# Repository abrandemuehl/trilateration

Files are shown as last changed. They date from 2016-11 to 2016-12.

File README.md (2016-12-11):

# Attempted ESP8266 Based WiFi Trilateration

This was a project done for UIUC's ECE 445 - Senior Design.

This project does not trilaterate positions succesfully - code for communication is still needed.

The program writes the MAC address and the associated RSSI of packets received in promiscuous mode to the UART connection at 115200 BAUD.
The messages are in a binary format found in `common/messages.h`.
They are read back by the PC program and displayed like so
```
WIFI:   6c:72:e7:d1:12:4d 40
Serial: 6c:72:e7:d1:12:4d 40
WIFI:   6c:72:e7:d1:12:4d 40
Serial: 6c:72:e7:d1:12:4d 40
WIFI:   6c:72:e7:d1:12:4d 40
Serial: 6c:72:e7:d1:12:4d 40
WIFI:   6c:72:e7:d1:12:4d 40
Serial: 6c:72:e7:d1:12:4d 40
WIFI:   6c:72:e7:d1:12:4d 40
Serial: 6c:72:e7:d1:3f:e2 6
WIFI:   6c:72:e7:d1:3f:e2 6
Serial: 6c:72:e7:d1:3f:e2 6
WIFI:   6c:72:e7:d1:3f:e2 6
Serial: 40:78:e7:d1:3f:e2 6
WIFI:   40:78:e7:d1:3f:e2 6
Serial: 2c:78:e7:d1:3f:e2 6
```
Messages prefaced with `WiFi` were received by the incomplete communication code.
The `Serial` came from the ESP8266.

There are some useful code snippets that can be used in other ESP8266 based projects.
The hardware design files also might be somewhat useful for reference.

The original goal of the project was to create a way to track WiFi devices indoors.
Our strategy was to enter promiscuous mode, and look at the RSSI of received packets, and use that to estimate the distance of the transmitting device from the ESP.

Boards were designed as part of the requirements for the class, but they are almost hardware equivalent to most simple ESP modules that you can purchase online for a lower price...
Also, the boards that we created have problems that we couldn't track down. We're pretty sure they were caused by poor fabrication, but there may be some flaw in the original designs.

## Building and running

Note: These instructions are for linux only.
We ran into issues with the toolchain on Mac that had to do with the size of the binary created not fitting into iram.

First, clone with the submodules included
```bash
$ git clone --recursive https://github.com/abrandemuehl/trilateration.git
```
Or, if you've already cloned it without submodules, use
```bash
$ git submodule update --init --recursive
```

Then, edit the makefile for the submodule [esp-open-sdk](https://github.com/pfalcon/esp-open-sdk) to use the 0.9.4 version.
This can be done by editing the line that says
```
VENDOR_SDK = x.x.x
```
to be
```
VENDOR_SDK = 0.9.4
```
then run `make` in the esp/esp-open-sdk directory. (This step takes a while)

Once that is complete, you can build the main app.

First, create a directory to hold the binary files `mkdir esp/bin`.

To build the main application, you first have to `source .env` to get the paths of the toolchain commands.
Once you've done that, run `make` in the `esp` directory.

Then you can run `make flash` to use the esptool to flash it onto the ESP8266 module of your choice that is in program mode.

## Strategy
Trilateration is a pretty simple concept.
You have 3 spheres in space with known radii, and you want to find the intersection point of all of the surfaces of the spheres.
You can use this strategy to get the location of a point, given the centers and radii of 3 spheres where the point lies on their surfaces.

See the [wikipedia](https://en.wikipedia.org/wiki/Trilateration) article and [this stackoverflow question](http://stackoverflow.com/questions/16176656/trilateration-and-locating-the-point-x-y-z) for more information about the algorithm.

The exact trilateration algorithm is implemented in `common/trilatertion.c`.

## ESP Specific Code

#### Promiscuous mode and MAC addresses
In order to use communicate the positions and radii of the circles estimated from the RSSI, each device must be identifiable through some means.
We chose the MAC address of devices, as this is *supposed* to be unique per device.
However, the information given to the promiscuous_rx_cb by the SDK is very limited on SDK versions >= 0.9.5.
It only passes some basic information about the packet to the callback, which does not include anything that can be used to identify the sender.
I'm not sure why they removed this functionality, but it exists in the SDK version 0.9.4, so we chose to use it.

When using SDK 0.9.4, we can get the whole 802.11 header of the packet, making it easy to get the MAC address of the sender and destination devices.
The basic structure of 802.11 packets is shown in `esp/network_80211.h` which we modified from the version found at https://github.com/ly0/esp8266-smartlink.
We added the structure of data frames, since that was what we wanted to use.

#### STATION mode and Promiscuous mode
The big problem we ran into with promiscuous mode was that the ESP must be in STATION mode for promiscuous mode to work.
This was a problem for our original design, since we planned to use the mesh networking capabilities of the ESP to communicate the positions and radii of the circles used for trilateration.

#### `rst cause:4`
Another problem we found was that the promiscuous mode callback runs at a high priority.
So, when you get more packets than you can process, the promiscuous callback will starve some other important task in the SDK (not sure which one) and cause a watchdog timer to reset the device.
The reset will cause the device to write `rst cause:4, boot mode: (x, x)` to the UART connection.
The `cause:4` indicates that the reset was caused by a watchdog timer going off, as documented [here](http://www.esp8266.com/viewtopic.php?p=2096#p2112).

The only way to mitigate this reset problem is to do less work in the promiscuous mode callback.
This doesn't mean you have to do less work total, you just need to delegate it to a lower priority task.

In the ESP sdk, tasks can be defined with the following lines of code
```C
#define message_procTaskPrio        1
#define message_procTaskQueueLen    2
os_event_t message_procTaskQueue[message_procTaskQueueLen];
static void message_procTask(os_event_t *event);

void ICACHE_FLASH_ATTR
user_init() {
  ...
  // Defines a task that can be started with system_os_post
  system_os_task(message_procTask, message_procTaskPrio,
                 message_procTaskQueue, message_procTaskQueueLen);
  ...
}
```

This defines, the task, but doesn't run it.
To run a task, run system_os_post in your promicuous mode callback.
```
void ICACHE_FLASH_ATTR
promisc_cb(uint8_t *buf, uint16_t len) {
  ...
  system_os_post(message_procTaskPrio, 0, 0);
  ...
}
```
When `system_os_post` is called, it will queue up the message processing task to be run once the CPU frees up from all of the system tasks that run at higher priority.

How you pass data to this task is up to you.
I used a ring buffer, but I didn't make it thread safe, so there are race conditions in there.

## PC Code

The PC code was added because of the STATION mode problem with promiscuous mode.
Without access points to connect to, each board would not be able to communicate with the other ones, making trilateration impossible.
We didn't want to require that the devices connect to a network, so we planned to send messages over USB to a laptop, then have the laptop broadcast the values.
We ran out of time before we could test if this method would work.

## Trilateration Problems
The trilateration algorithm and code that we had intended to use would not with real values based on RSSI.
The algorithm solves a system of equations using the spheres, but only finds a solution if they intersect at only one point.
This is not a good algorithm because it doesn't find a solution when the estimated spheres don't exactly line up, which won't happen in almost all cases.

## In conclusion

We ran out of time and couldn't finish the project for the class.
We have no intentions of working on this code again, but if you have any questions about the choices made in the code, feel free to open an issue.

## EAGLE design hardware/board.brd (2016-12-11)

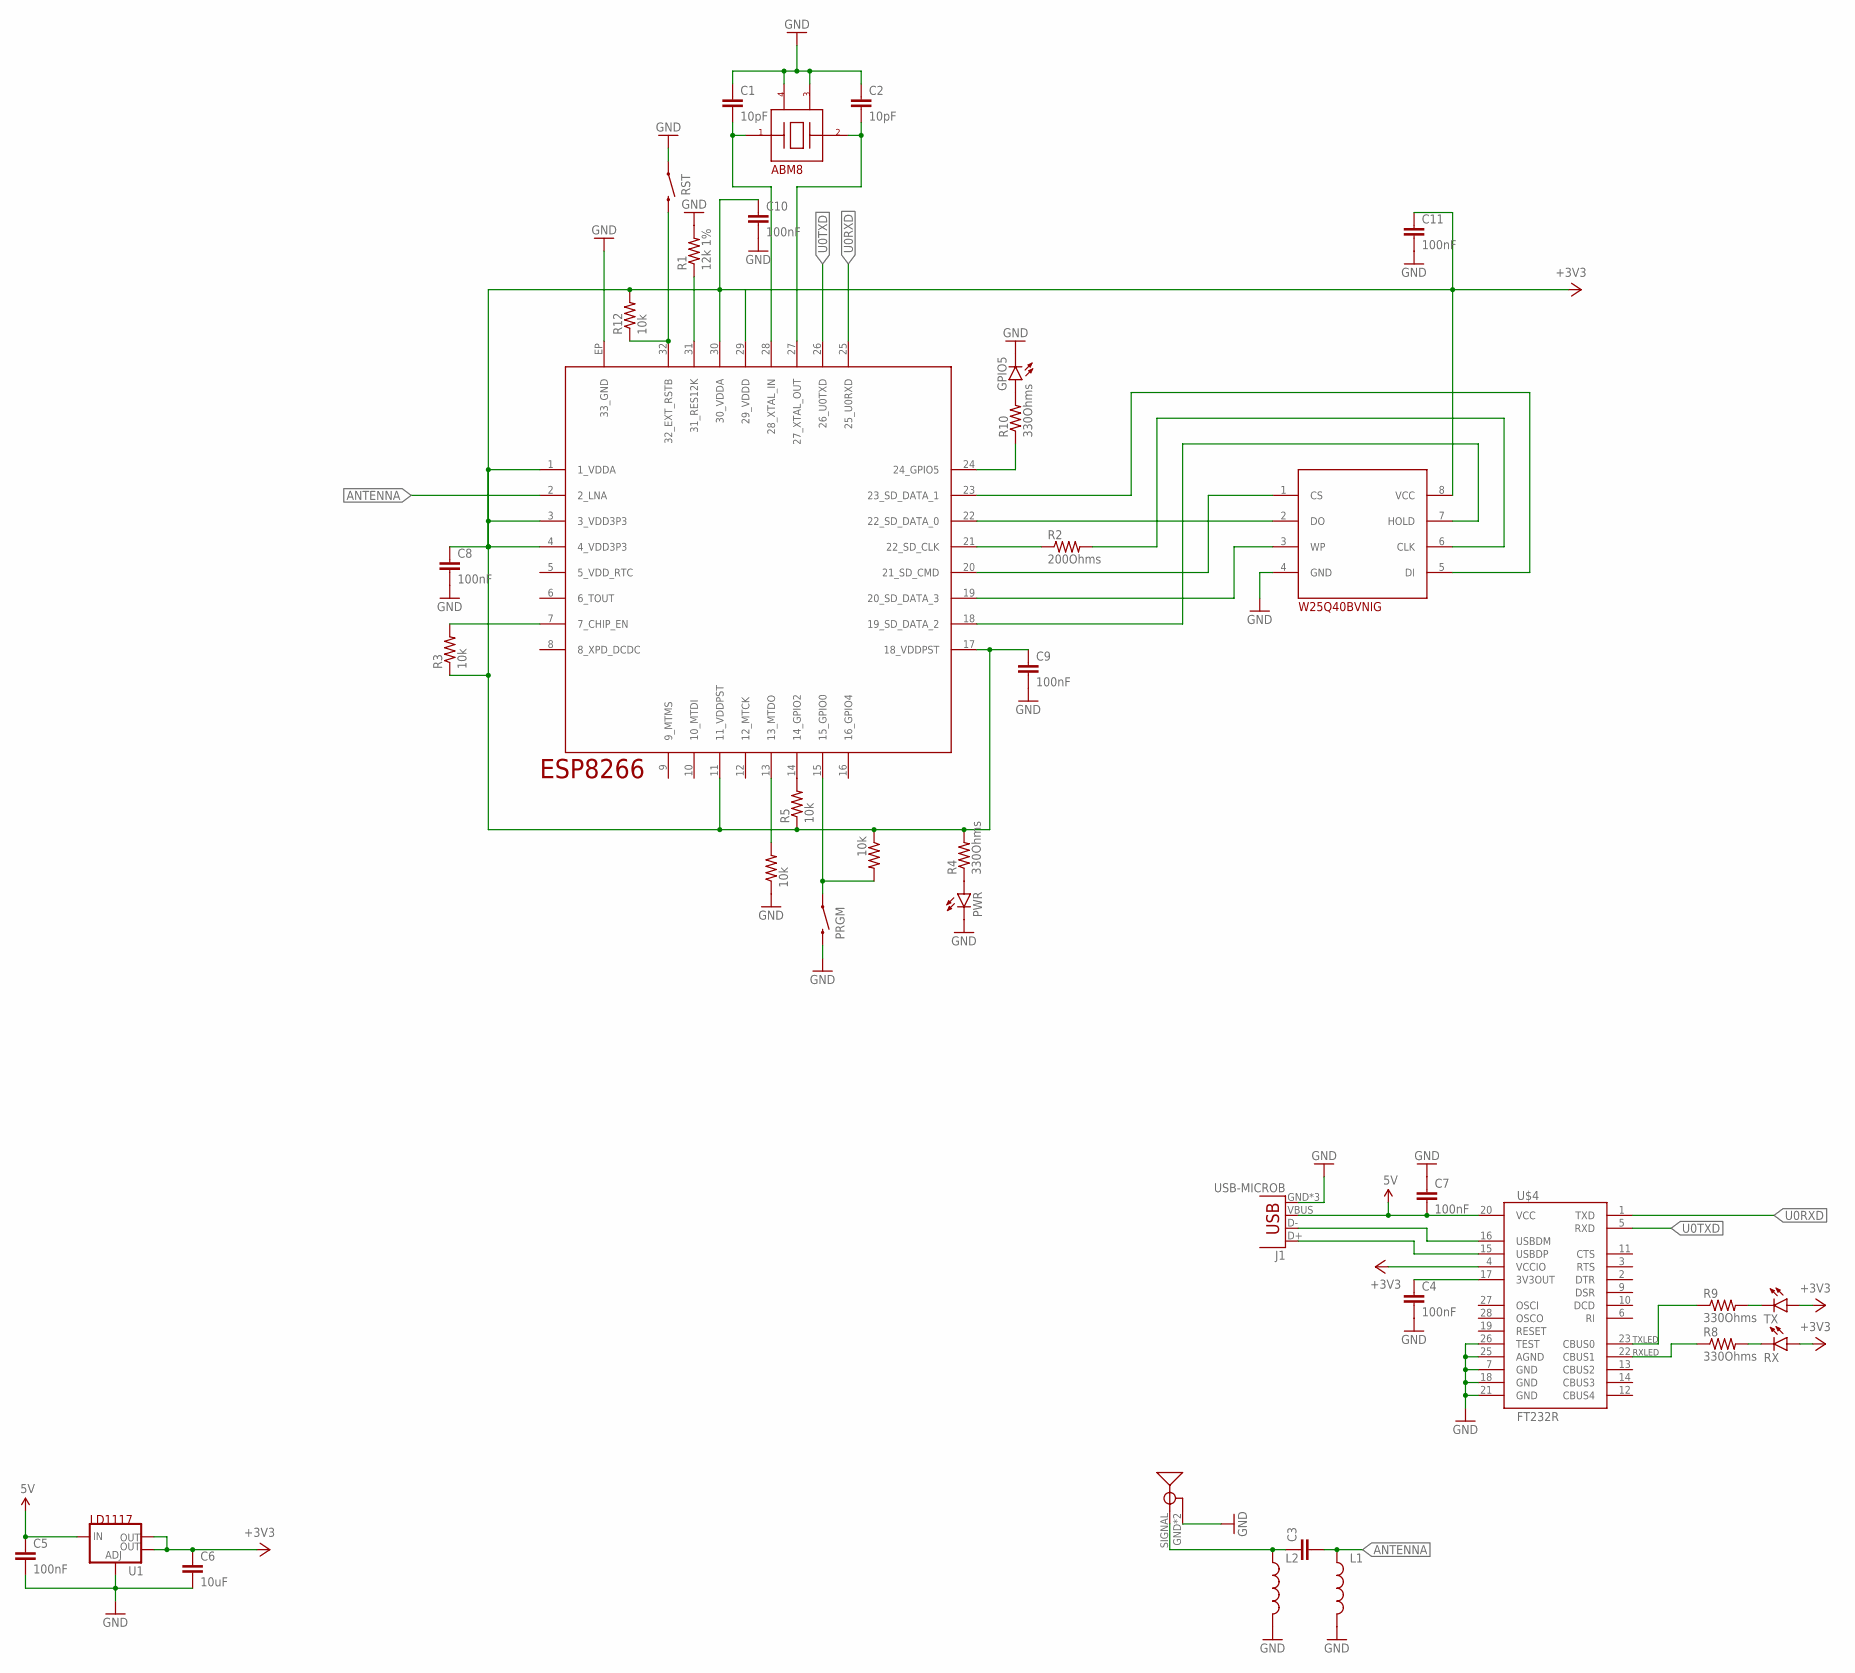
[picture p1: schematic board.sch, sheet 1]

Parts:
C1, C2: 10pF; 0603-CAP
C3: CAP0402-CAP; 0402-CAP
C4, C5, C7, C8, C9, C10, C11: 100nF; 0603-CAP
C6: 10uF; 0603-CAP
GPIO5: LED0603; LED-0603
J1: USB-MICROB
L1, L2: INDUCTOR0402; C0402
PRGM: SWITCH-MOMENTARY-2PTH; TACTILE-PTH
PWR: LED0603; LED-0603
R1: 12k 1%; 0603-RES
R2: 200Ohms; 0402-RES
R3, R5, R6, R7, R12: 10k; 0603-RES
R4, R8, R9, R10: 330Ohms; 0603-RES
RST: SWITCH-MOMENTARY-2PTH; TACTILE-PTH
RX: LED0603; LED-0603
TX: LED0603; LED-0603
U1: V_REG_LM1117SOT223; SOT223
U$1: W25Q40BVNIG; SOIC-8
U$2: ESP8266; QFN-32
U$3: ABM8
U$4: FT232R; SSOP-28
U$5: OMNIANTENNA; ANTENNA

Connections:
+3V3: C6.1, C8.1, C9.1, C10.1, C11.1, R3.1, R4.2, R5.1, R6.1, R12.2, RX.A, TX.A, U1.2 (OUT), U1.4 (OUT), U$1.8 (VCC), U$2.1 (1_VDDA), U$2.3 (3_VDD3P3), U$2.4 (4_VDD3P3), U$2.11 (11_VDDPST), U$2.17 (18_VDDPST), U$2.29 (29_VDDD), U$2.30 (30_VDDA), U$4.4 (VCCIO)
ANTENNA: C3.2, L1.1, U$2.2 (2_LNA)
GND: C1.1, C2.1, C4.2, C5.2, C6.2, C7.1, C8.2, C9.2, C10.2, C11.2, GPIO5.C, J1.GND, J1.MT1 (GND), J1.MT2 (GND), L1.2, L2.2, PRGM.3 (2), PWR.C, R1.2, R7.1, RST.1, U1.1 (ADJ), U$1.4 (GND), U$2.EP (33_GND), U$3.P$2 (GND), U$3.P$4 (GND2), U$4.7 (GND), U$4.18 (GND), U$4.21 (GND), U$4.25 (AGND), U$4.26 (TEST), U$5.GND, U$5.GND1 (GND)
unnamed: R2.2, U$1.6 (CLK)
unnamed: U$1.2 (DO), U$2.22 (22_SD_DATA_0)
unnamed: U$1.5 (DI), U$2.23 (23_SD_DATA_1)
unnamed: U$1.7 (HOLD), U$2.18 (19_SD_DATA_2)
unnamed: R1.1, U$2.31 (31_RES12K)
unnamed: U$1.3 (WP), U$2.19 (20_SD_DATA_3)
unnamed: U$1.1 (CS), U$2.20 (21_SD_CMD)
unnamed: R2.1, U$2.21 (22_SD_CLK)
unnamed: C3.1, L2.1, U$5.SIGNAL
unnamed: R3.2, U$2.7 (7_CHIP_EN)
unnamed: PWR.A, R4.1
unnamed: R5.2, U$2.14 (14_GPIO2)
unnamed: C4.1, U$4.17 (3V3OUT)
unnamed: R7.2, U$2.13 (13_MTDO)
unnamed: J1.D+, U$4.15 (USBDP)
unnamed: J1.D-, U$4.16 (USBDM)
unnamed: R8.1, U$4.22 (CBUS1)
unnamed: R9.1, U$4.23 (CBUS0)
unnamed: R9.2, TX.C
unnamed: PRGM.1, R6.2, U$2.15 (15_GPIO0)
unnamed: GPIO5.A, R10.2
unnamed: R10.1, U$2.24 (24_GPIO5)
unnamed: R12.1, RST.3 (2), U$2.32 (32_EXT_RSTB)
RX: R8.2, RX.C
U0RXD: U$2.25 (25_U0RXD), U$4.1 (TXD)
U0TXD: U$2.26 (26_U0TXD), U$4.5 (RXD)
VUSB: C5.1, C7.2, J1.VBUS, U1.3 (IN), U$4.20 (VCC)
XTAL_IN: C1.2, U$2.28 (28_XTAL_IN), U$3.P$1 (IN)
XTAL_OUT: C2.2, U$2.27 (27_XTAL_OUT), U$3.P$3 (OUT)

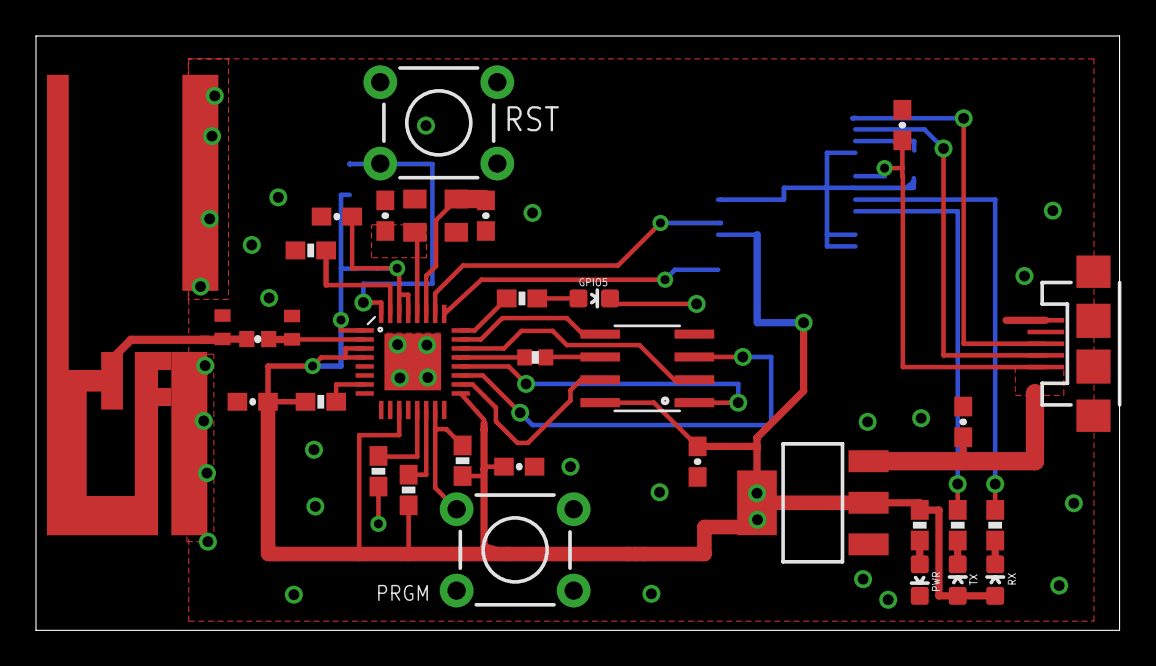
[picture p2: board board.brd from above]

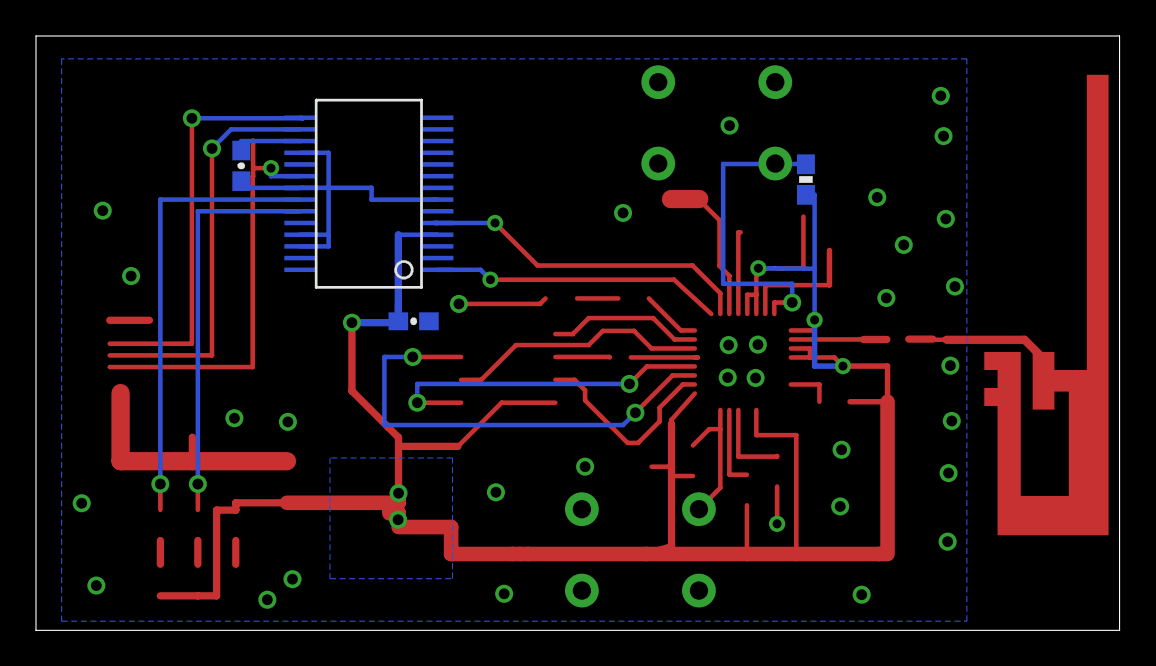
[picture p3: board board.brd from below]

Board: 2 copper layers, 60.2 x 33.0 mm, 37 parts (4 on the bottom side), 32 nets.

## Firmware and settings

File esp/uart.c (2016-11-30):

/*
 * File	: uart.c
 * This file is part of Espressif's AT+ command set program.
 * Copyright (C) 2013 - 2016, Espressif Systems
 *
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
 * You should have received a copy of the GNU General Public License along
 * with this program.  If not, see <http://www.gnu.org/licenses/>.
 */
#include "ets_sys.h"
#include "osapi.h"
#include "uart.h"
#include "osapi.h"
#include "uart_register.h"
//#include "ssc.h"


#define recvTaskPrio        3
#define recvTaskQueueLen    64
// UartDev is defined and initialized in rom code.
extern UartDevice    UartDev;
//extern os_event_t    at_recvTaskQueue[at_recvTaskQueueLen];

LOCAL void uart0_rx_intr_handler(void *para);

/******************************************************************************
 * FunctionName : uart_config
 * Description  : Internal used function
 *                UART0 used for data TX/RX, RX buffer size is 0x100, interrupt enabled
 *                UART1 just used for debug output
 * Parameters   : uart_no, use UART0 or UART1 defined ahead
 * Returns      : NONE
*******************************************************************************/
LOCAL void ICACHE_FLASH_ATTR
uart_config(uint8 uart_no)
{
  if (uart_no == UART1)
  {
    PIN_FUNC_SELECT(PERIPHS_IO_MUX_GPIO2_U, FUNC_U1TXD_BK);
  }
  else
  {
    /* rcv_buff size if 0x100 */
    ETS_UART_INTR_ATTACH(uart0_rx_intr_handler,  &(UartDev.rcv_buff));
    PIN_PULLUP_DIS(PERIPHS_IO_MUX_U0TXD_U);
    PIN_FUNC_SELECT(PERIPHS_IO_MUX_U0TXD_U, FUNC_U0TXD);
    PIN_FUNC_SELECT(PERIPHS_IO_MUX_MTDO_U, FUNC_U0RTS);
  }

  uart_div_modify(uart_no, UART_CLK_FREQ / (UartDev.baut_rate));

  if (uart_no == UART1)  //UART 1 always 8 N 1
	  WRITE_PERI_REG(UART_CONF0(uart_no), CALC_UARTMODE(EIGHT_BITS, NONE_BITS, ONE_STOP_BIT));
  else
	  WRITE_PERI_REG(UART_CONF0(uart_no), CALC_UARTMODE(UartDev.data_bits, UartDev.parity, UartDev.stop_bits));

  //clear rx and tx fifo,not ready
  SET_PERI_REG_MASK(UART_CONF0(uart_no), UART_RXFIFO_RST | UART_TXFIFO_RST);
  CLEAR_PERI_REG_MASK(UART_CONF0(uart_no), UART_RXFIFO_RST | UART_TXFIFO_RST);

  //set rx fifo trigger
//  WRITE_PERI_REG(UART_CONF1(uart_no),
//                 ((UartDev.rcv_buff.TrigLvl & UART_RXFIFO_FULL_THRHD) << UART_RXFIFO_FULL_THRHD_S) |
//                 ((96 & UART_TXFIFO_EMPTY_THRHD) << UART_TXFIFO_EMPTY_THRHD_S) |
//                 UART_RX_FLOW_EN);
  if (uart_no == UART0)
  {
    //set rx fifo trigger
    WRITE_PERI_REG(UART_CONF1(uart_no),
                   ((0x10 & UART_RXFIFO_FULL_THRHD) << UART_RXFIFO_FULL_THRHD_S) |
                   ((0x10 & UART_RX_FLOW_THRHD) << UART_RX_FLOW_THRHD_S) |
                   UART_RX_FLOW_EN |
                   (0x02 & UART_RX_TOUT_THRHD) << UART_RX_TOUT_THRHD_S |
                   UART_RX_TOUT_EN);
    SET_PERI_REG_MASK(UART_INT_ENA(uart_no), UART_RXFIFO_TOUT_INT_ENA |
                      UART_FRM_ERR_INT_ENA);
  }
  else
  {
    WRITE_PERI_REG(UART_CONF1(uart_no),
                   ((UartDev.rcv_buff.TrigLvl & UART_RXFIFO_FULL_THRHD) << UART_RXFIFO_FULL_THRHD_S));
  }

  //clear all interrupt
  WRITE_PERI_REG(UART_INT_CLR(uart_no), 0xffff);
  //enable rx_interrupt
  SET_PERI_REG_MASK(UART_INT_ENA(uart_no), UART_RXFIFO_FULL_INT_ENA);
}

/******************************************************************************
 * FunctionName : uart1_tx_one_char
 * Description  : Internal used function
 *                Use uart1 interface to transfer one char
 * Parameters   : uint8 TxChar - character to tx
 * Returns      : OK
*******************************************************************************/
LOCAL STATUS
uart_tx_one_char(uint8 uart, uint8 TxChar)
{
    while (true)
    {
      uint32 fifo_cnt = READ_PERI_REG(UART_STATUS(uart)) & (UART_TXFIFO_CNT<<UART_TXFIFO_CNT_S);
      if ((fifo_cnt >> UART_TXFIFO_CNT_S & UART_TXFIFO_CNT) < 126) {
        break;
      }
    }

    WRITE_PERI_REG(UART_FIFO(uart) , TxChar);
    return OK;
}

/******************************************************************************
 * FunctionName : uart1_write_char
 * Description  : Internal used function
 *                Do some special deal while tx char is '\r' or '\n'
 * Parameters   : char c - character to tx
 * Returns      : NONE
*******************************************************************************/
LOCAL void ICACHE_FLASH_ATTR
uart1_write_char(char c)
{
  if (c == '\n')
  {
    uart_tx_one_char(UART1, '\r');
    uart_tx_one_char(UART1, '\n');
  }
  else if (c == '\r')
  {
  }
  else
  {
    uart_tx_one_char(UART1, c);
  }
}
/******************************************************************************
 * FunctionName : uart0_tx_buffer
 * Description  : use uart0 to transfer buffer
 * Parameters   : uint8 *buf - point to send buffer
 *                uint16 len - buffer len
 * Returns      :
*******************************************************************************/
void ICACHE_FLASH_ATTR
uart0_tx_buffer(uint8 *buf, uint16 len)
{
  uint16 i;

  for (i = 0; i < len; i++)
  {
    uart_tx_one_char(UART0, buf[i]);
  }
}

/******************************************************************************
 * FunctionName : uart0_sendStr
 * Description  : use uart0 to transfer buffer
 * Parameters   : uint8 *buf - point to send buffer
 *                uint16 len - buffer len
 * Returns      :
*******************************************************************************/
void ICACHE_FLASH_ATTR
uart0_sendStr(const char *str)
{
	while(*str)
	{
		uart_tx_one_char(UART0, *str++);
	}
}

/******************************************************************************
 * FunctionName : uart0_rx_intr_handler
 * Description  : Internal used function
 *                UART0 interrupt handler, add self handle code inside
 * Parameters   : void *para - point to ETS_UART_INTR_ATTACH's arg
 * Returns      : NONE
*******************************************************************************/
//extern void at_recvTask(void);

LOCAL void
uart0_rx_intr_handler(void *para)
{
  /* uart0 and uart1 intr combine togther, when interrupt occur, see reg 0x3ff20020, bit2, bit0 represents
    * uart1 and uart0 respectively
    */
//  RcvMsgBuff *pRxBuff = (RcvMsgBuff *)para;
  uint8 RcvChar;
  uint8 uart_no = UART0;//UartDev.buff_uart_no;
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

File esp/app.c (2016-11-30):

#include "osapi.h"
#include "ets_sys.h"
#include "user_config.h"
#include "user_interface.h"
#include "network_80211.h"
#include "mem.h"

#include "uart.h"
#include "../common/messages.h"
#include "ringbuffer.h"

#define CHANNEL 1
#define NUM_NODES 3

#define MAC_CMP(a, b) \
  (a[0] == b[0] && a[1] == b[1] && a[2] == b[2] && \
   a[3] == b[3] && a[4] == b[4] && a[5] == b[5])



// #define uart_procTaskPrio        2
#define uart_procTaskQueueLen    2
os_event_t uart_procTaskQueue[uart_procTaskQueueLen];
static void uart_procTask(os_event_t *event);

#define message_procTaskPrio        1
#define message_procTaskQueueLen    2
os_event_t message_procTaskQueue[message_procTaskQueueLen];
static void message_procTask(os_event_t *event);


#define process_procTaskPrio        0
#define process_procTaskQueueLen    64
os_event_t process_procTaskQueue[process_procTaskQueueLen];
static void process_procTask(os_event_t *event);


#define PRINT_MAC(mac) \
    os_printf("%02x:%02x:%02x:%02x:%02x:%02x", mac[0], mac[1], mac[2], mac[3], mac[4], mac[5]);

// Nodes x, y and z position
float xloc, yloc, zloc;

uint32_t chip_ids[NUM_NODES];
int num_chips = 1;

struct entry {
  uint8_t mac[6];
  int8_t rssi[NUM_NODES];
  uint32_t time;
};

struct entry entries[100];
size_t entries_end = 0;

RingBuffer updates;

void ICACHE_FLASH_ATTR
promisc_cb(uint8_t *buf, uint16_t len)
{
  if (len < 64) {
    return;
  }
  struct sniffer_buf *sniffer = (struct sniffer_buf*)buf;
  struct framectrl_80211 *fc = (struct framectrl_80211*)sniffer->buf;
  if(fc->Type == FRAME_TYPE_DATA) {
    struct data_frame_80211 *data_frame = (struct data_frame_80211*)sniffer->buf;

    int8_t rssi = sniffer->rx_ctrl.rssi;
    uint32_t time = system_get_time();
    // Search for the mac entry
    int ptr;
    for(ptr = 0; ptr < entries_end; ptr++) {
      if(MAC_CMP(entries[ptr].mac, data_frame->sa)) {
        // Found. Update value
        entries[ptr].time = time;
        entries[ptr].rssi[0] = rssi;
        break;
      }
    }
    if(ptr == entries_end) {
      // Insert a new entry
      os_memcpy(entries[ptr].mac, data_frame->sa, sizeof(entries[ptr].mac));
      entries[ptr].rssi[0] = rssi;
      entries[ptr].time = time;
      entries_end++;
    }

    // Put the new position into the ringbuffer as been updated
    rb_push(&updates, ptr);
    system_os_post(message_procTaskPrio, 0, 0);
  }
}



// Send updates over uart
void ICACHE_FLASH_ATTR
message_procTask(os_event_t *event) {
  message m;

  int idx = rb_get(&updates);
  message_create(&m, system_get_chip_id(), entries[idx].mac, entries[idx].rssi[0]);
  uart0_tx_buffer((uint8_t *)&m, sizeof(m));

  idx = rb_get(&updates);
}

void ICACHE_FLASH_ATTR
sniffer_init(void)
{
  // Set up promiscuous callback
  wifi_set_channel(CHANNEL);
  wifi_promiscuous_enable(0);
  wifi_set_promiscuous_rx_cb(promisc_cb);
  wifi_promiscuous_enable(1);
  os_printf("Started\n");
}


message *msg = NULL;
int uart_index = 0;
static void uart_procTask(os_event_t *event) {
  return;
  if(msg == NULL) {
    msg = (message *)os_malloc(sizeof(message));
  }
  uint8_t *buf = (uint8_t *)msg;
  buf[uart_index] = event->par;
  switch (uart_index) {
    case 0:
      if(buf[uart_index] == 'f') {
        uart_index++;
      }
      break;
    case 1:
      if(buf[uart_index] == 'd') {
        uart_index++;
      }
      break;
    case 2:
      if(buf[uart_index] == 'a') {
        uart_index++;
      }
      break;
    default:
      if(++uart_index >= sizeof(message)) {
        uart_index = 0;
        // Copy the message into the ring buffer
        system_os_post(process_procTaskPrio, 0, (os_param_t)msg);
        msg = (message *)os_malloc(sizeof(message));
      }
      break;
  }
}

static void process_procTask(os_event_t *event) {
  message *m = (message *)event->par;

  // Find chip_id
  int i;
  int chip_idx = -1;
  for(i=0; i < num_chips; i++) {
    if(chip_ids[i] == m->src_id) {
      chip_idx = i;
      break;
    }
  }
  if(chip_idx == -1) {
    if(num_chips == 3) {
      // No more chips left. Return
      return;
    }
    // Add chip to the chip list
    chip_ids[num_chips] = m->src_id;
  }

  for(i = 0; i < entries_end; i++) {
    if(MAC_CMP(entries[i].mac, m->mac)) {
      // Found. Update value
      entries[i].rssi[chip_idx] = m->rssi;
      break;
    }
  }
  if(i == entries_end) {
    // Insert a new entry
    os_memcpy(entries[i].mac, m->mac, sizeof(entries[i].mac));
    entries[i].rssi[chip_idx] = m->rssi;
    entries_end++;
  }
  os_free(m);
}

  void ICACHE_FLASH_ATTR
user_init()
{
  /* uart_div_modify(0, UART_CLK_FREQ / 115200); */
  uart_init(BIT_RATE_115200,BIT_RATE_115200);

  // Promiscuous works only with station mode
  wifi_set_opmode(STATION_MODE);

  os_memset(entries, 0, sizeof(entries));
  rb_init(&updates);
  system_init_done_cb(sniffer_init);

  chip_ids[0] = system_get_chip_id();

  // rb_init(&messages);

  uint8_t comm_start[100] = {0xFF};
  comm_start[99] = 0;

  system_os_task(message_procTask, message_procTaskPrio, message_procTaskQueue, message_procTaskQueueLen);
  system_os_task(uart_procTask, uart_procTaskPrio, uart_procTaskQueue, uart_procTaskQueueLen);


  system_os_task(process_procTask, process_procTaskPrio, process_procTaskQueue, process_procTaskQueueLen);
  os_printf("Starting\n");
}

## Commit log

2016-11-24 Add arduino code
2016-11-29 UART driver files
2016-12-11 Add hardware design files
    [board.brd, board.sch]

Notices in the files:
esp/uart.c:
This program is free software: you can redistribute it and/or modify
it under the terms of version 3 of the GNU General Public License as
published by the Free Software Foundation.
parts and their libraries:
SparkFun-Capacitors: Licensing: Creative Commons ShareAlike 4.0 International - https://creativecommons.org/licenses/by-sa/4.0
